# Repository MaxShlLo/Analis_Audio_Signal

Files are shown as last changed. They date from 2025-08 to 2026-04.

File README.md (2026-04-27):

# 🎵 Аудіо Спектроаналізатор

**Аудіо спектроаналізатор** — це пристрій, який візуалізує навколишній звук у реальному часі. 

За допомогою мікрофона він вловлює звуки із зовнішнього середовища (музику з колонок, голос, шум). Мікроконтролер оцифровує цей аналоговий сигнал, обробляє його за допомогою алгоритму Швидкого перетворення Фур'є (FFT) і виводить результат — спектр частот від басів до високих нот — на чотири світлодіодні матриці 8х8 у вигляді динамічних стовпчиків.

---
## 📂 Структура проєкту
- 📂 **Analis_Audio_Signal_ARDUINO** — Початкова версія коду для плат Arduino.
- 📂 **Audio_Spectrum_Analyzer_AltiumDesigner** — Схема та трасування друкованої плати (PCB), розроблена в Altium Designer.
- 📂 **vs-code** — Оптимізований модульний C-код для мікроконтролера STM8S103F3P6, налаштований для збірки через VS Code.

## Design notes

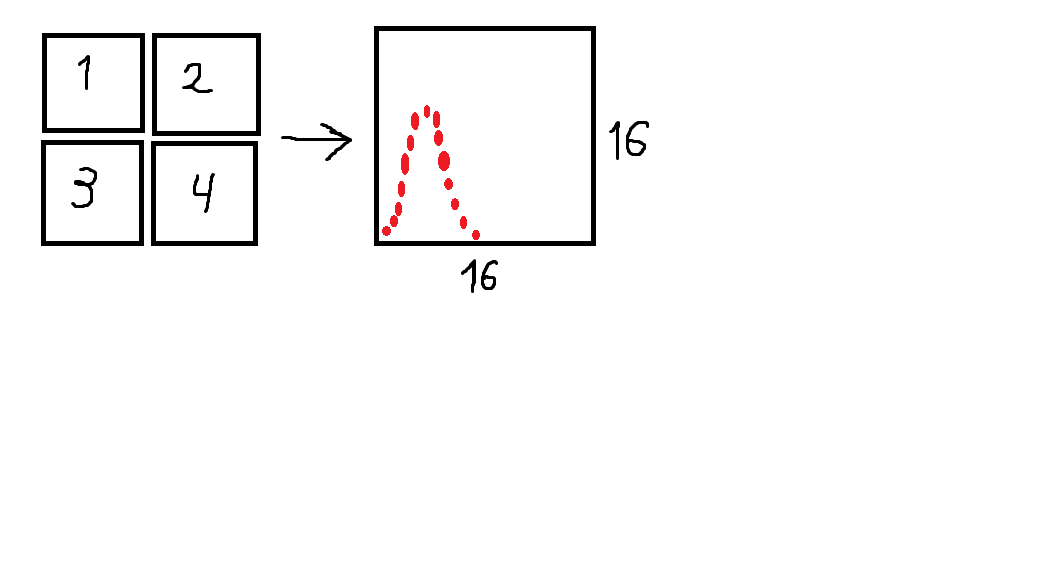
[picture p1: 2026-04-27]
FHT.png

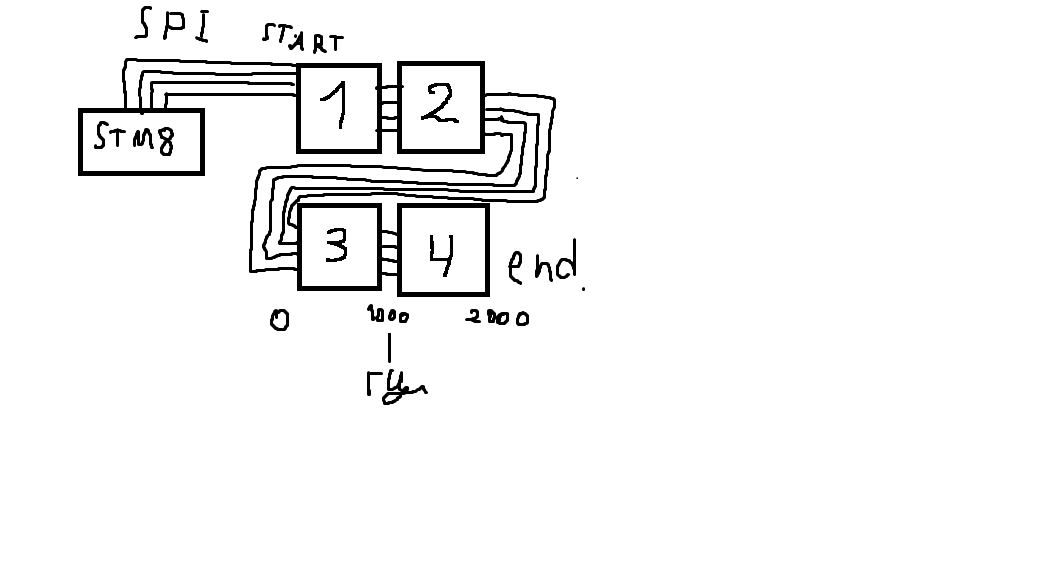
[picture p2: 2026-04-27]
SPI.png

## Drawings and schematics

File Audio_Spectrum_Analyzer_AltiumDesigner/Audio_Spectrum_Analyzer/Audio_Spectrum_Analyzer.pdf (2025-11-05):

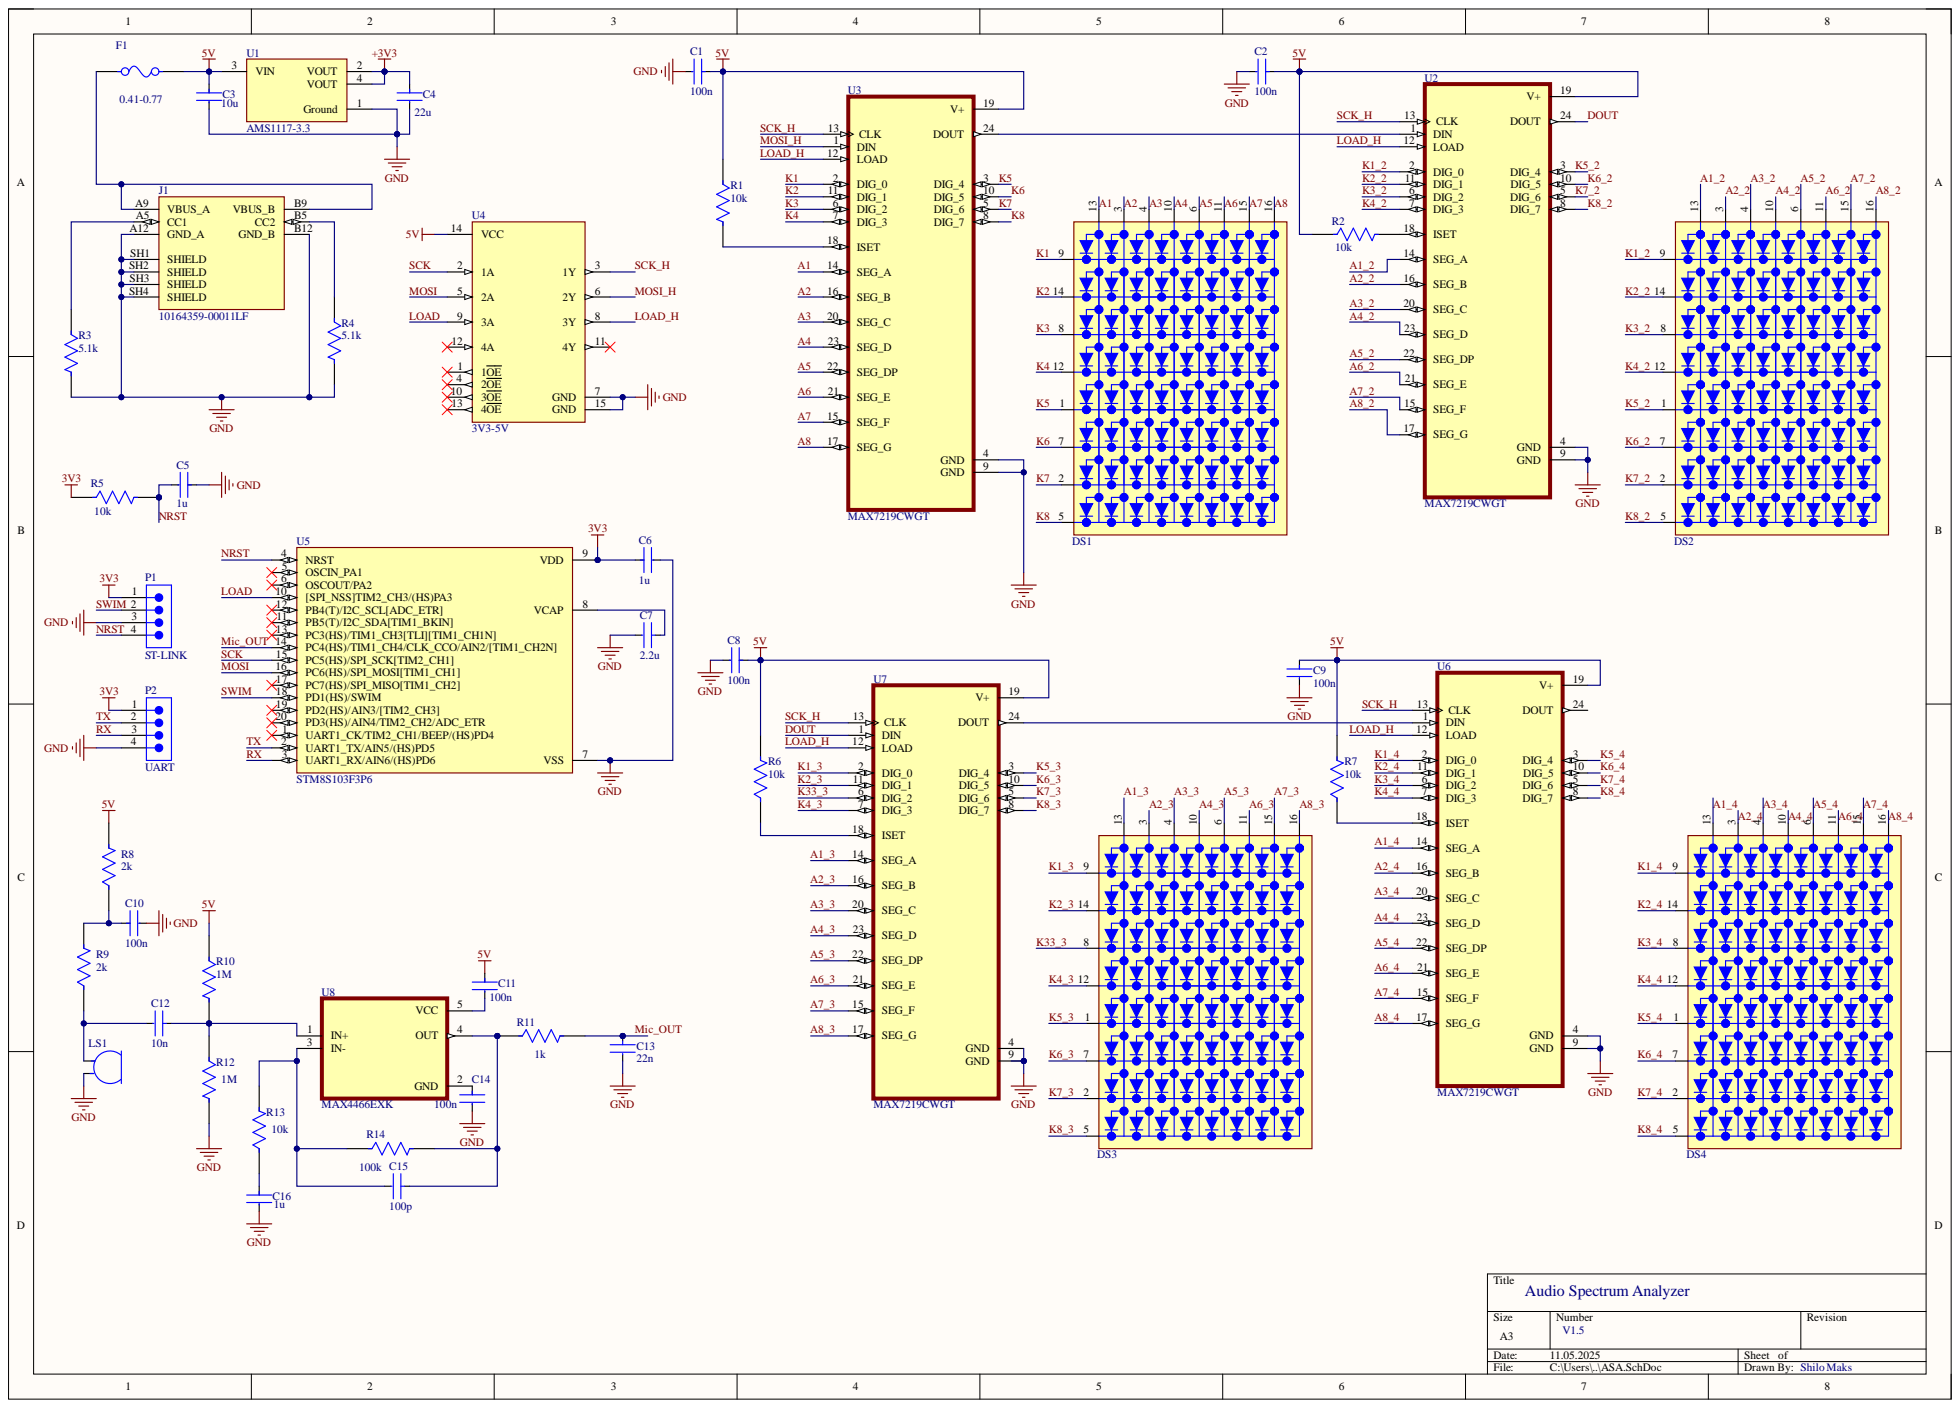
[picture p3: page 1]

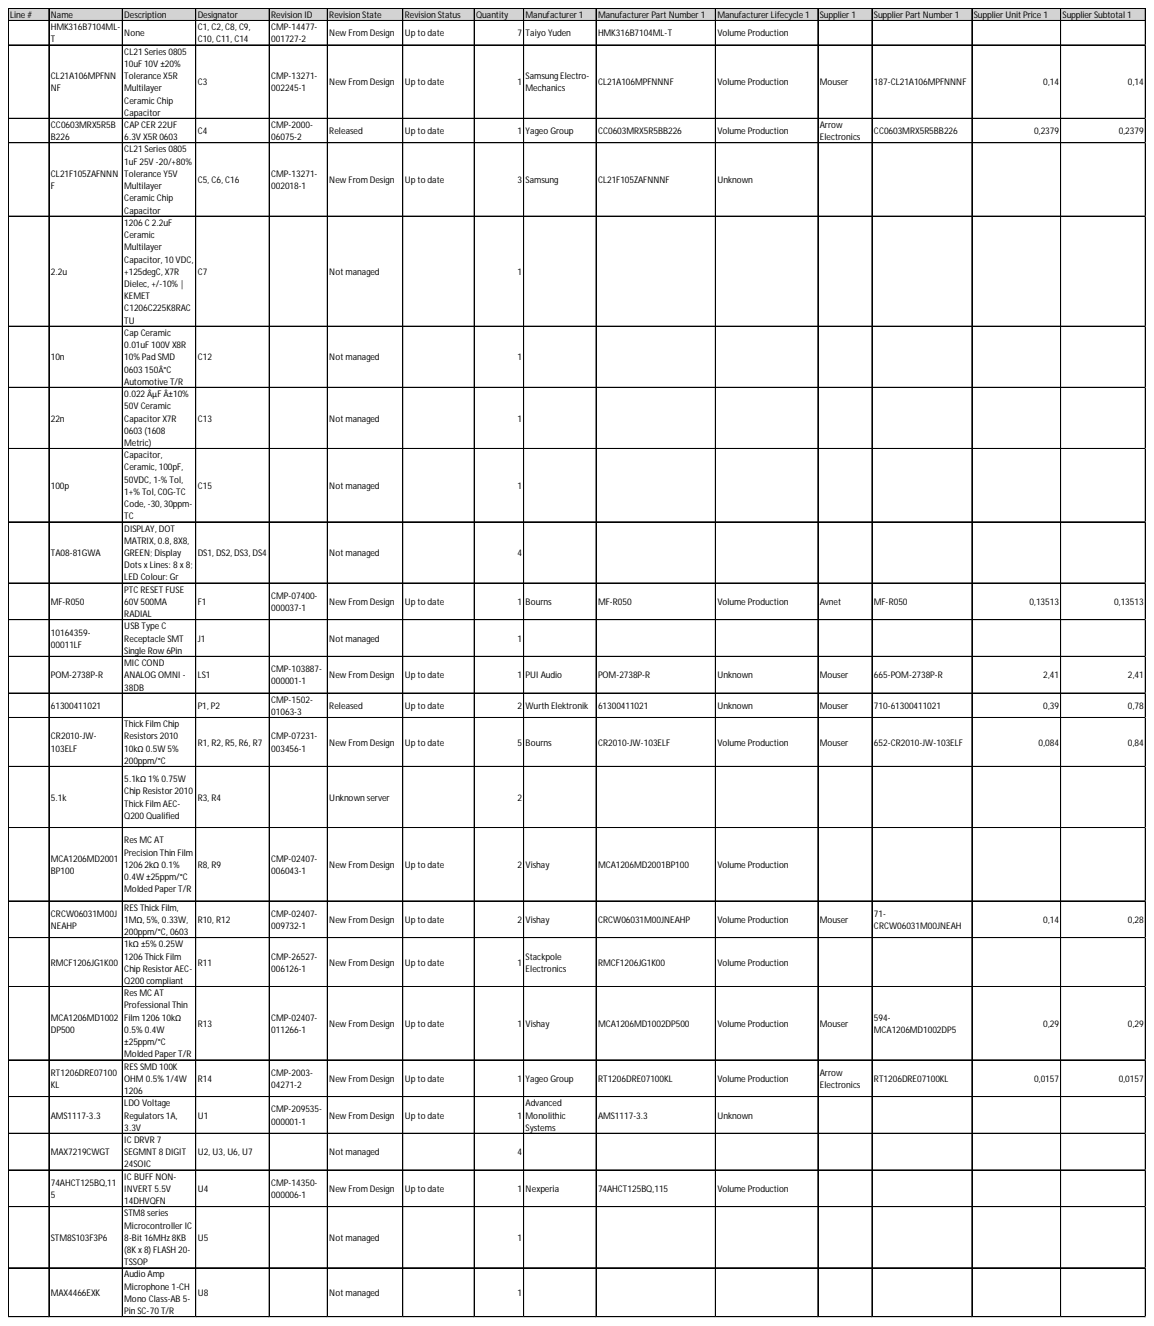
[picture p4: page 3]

Line # | Name | Description | Designator | Revision ID | Revision State | Revision Status | Quantity | Manufacturer 1 | Manufacturer Part Number 1 | Manufacturer Lifecycle 1 | Supplier 1 | Supplier Part Number 1 | Supplier Unit Price 1 | Supplier Subtotal 1

HMK316B7104ML-T | None | C1, C2, C8, C9, C10, C11, C14 | CMP-14477-001727-2 | New From Design | Up to date | 7 | Taiyo Yuden | HMK316B7104ML-T | Volume Production

CL21A106MPFNN NF | CL21 Series 0805 10uF 10V ±20% Tolerance X5R Multilayer Ceramic Chip Capacitor | C3 | CMP-13271-002245-1 | New From Design | Up to date | 1 | Samsung Electro-Mechanics | CL21A106MPFNNNF | Volume Production | Mouser | 187-CL21A106MPFNNNF | 0,14 | 0,14

CC0603MRX5R5B B226 | CAP CER 22UF 6.3V X5R 0603 | C4 | CMP-2000-06075-2 | Released | Up to date | 1 | Yageo Group | CC0603MRX5R5BB226 | Volume Production | Arrow Electronics | CC0603MRX5R5BB226 | 0,2379 | 0,2379

CL21F105ZAFNNN F | CL21 Series 0805 1uF 25V -20/+80% Tolerance Y5V Multilayer Ceramic Chip Capacitor | C5, C6, C16 | CMP-13271-002018-1 | New From Design | Up to date | 3 | Samsung | CL21F105ZAFNNNF | Unknown

2.2u | 1206 C 2.2uF Ceramic Multilayer Capacitor, 10 VDC, +125degC, X7R Dielec, +/-10% | KEMET C1206C225K8RAC TU | C7 | | Not managed | | 1

10n | Cap Ceramic 0.01uF 100V X8R 10% Pad SMD 0603 150Â°C Automotive T/R | C12 | | Not managed | | 1

22n | 0.022 ÂµF Â±10% 50V Ceramic Capacitor X7R 0603 (1608 Metric) | C13 | | Not managed | | 1

100p | Capacitor, Ceramic, 100pF, 50VDC, 1-% Tol, 1+% Tol, C0G-TC Code, -30, 30ppm-TC | C15 | | Not managed | | 1

TA08-81GWA | DISPLAY, DOT MATRIX, 0.8, 8X8, GREEN; Display Dots x Lines: 8 x 8; LED Colour: Gr | DS1, DS2, DS3, DS4 | | Not managed | | 4

MF-R050 | PTC RESET FUSE 60V 500MA RADIAL | F1 | CMP-07400-000037-1 | New From Design | Up to date | 1 | Bourns | MF-R050 | Volume Production | Avnet | MF-R050 | 0,13513 | 0,13513

10164359-00011LF | USB Type C Receptacle SMT Single Row 6Pin | J1 | | Not managed | | 1

POM-2738P-R | MIC COND ANALOG OMNI -38DB | LS1 | CMP-103887-000001-1 | New From Design | Up to date | 1 | PUI Audio | POM-2738P-R | Unknown | Mouser | 665-POM-2738P-R | 2,41 | 2,41

61300411021 | | P1, P2 | CMP-1502-01063-3 | Released | Up to date | 2 | Wurth Elektronik | 61300411021 | Unknown | Mouser | 710-61300411021 | 0,39 | 0,78

CR2010-JW-103ELF | Thick Film Chip Resistors 2010 10kΩ 0.5W 5% 200ppm/°C | R1, R2, R5, R6, R7 | CMP-07231-003456-1 | New From Design | Up to date | 5 | Bourns | CR2010-JW-103ELF | Volume Production | Mouser | 652-CR2010-JW-103ELF | 0,084 | 0,84

5.1k | 5.1kΩ 1% 0.75W Chip Resistor 2010 Thick Film AEC-Q200 Qualified | R3, R4 | | Unknown server | | 2

MCA1206MD2001 BP100 | Res MC AT Precision Thin Film 1206 2kΩ 0.1% 0.4W ±25ppm/°C Molded Paper T/R | R8, R9 | CMP-02407-006043-1 | New From Design | Up to date | 2 | Vishay | MCA1206MD2001BP100 | Volume Production

CRCW06031M00J NEAHP | RES Thick Film, 1MΩ, 5%, 0.33W, 200ppm/°C, 0603 | R10, R12 | CMP-02407-009732-1 | New From Design | Up to date | 2 | Vishay | CRCW06031M00JNEAHP | Volume Production | Mouser | 71-CRCW06031M00JNEAH | 0,14 | 0,28

RMCF1206JG1K00 | 1kΩ ±5% 0.25W 1206 Thick Film Chip Resistor AEC-Q200 compliant | R11 | CMP-26527-006126-1 | New From Design | Up to date | 1 | Stackpole Electronics | RMCF1206JG1K00 | Volume Production

MCA1206MD1002 DP500 | Res MC AT Professional Thin Film 1206 10kΩ 0.5% 0.4W ±25ppm/°C Molded Paper T/R | R13 | CMP-02407-011266-1 | New From Design | Up to date | 1 | Vishay | MCA1206MD1002DP500 | Volume Production | Mouser | 594-MCA1206MD1002DP5 | 0,29 | 0,29

RT1206DRE07100 KL | RES SMD 100K OHM 0.5% 1/4W 1206 | R14 | CMP-2003-04271-2 | New From Design | Up to date | 1 | Yageo Group | RT1206DRE07100KL | Volume Production | Arrow Electronics | RT1206DRE07100KL | 0,0157 | 0,0157

AMS1117-3.3 | LDO Voltage Regulators 1A, 3.3V | U1 | CMP-209535-000001-1 | New From Design | Up to date | 1 | Advanced Monolithic Systems | AMS1117-3.3 | Unknown

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

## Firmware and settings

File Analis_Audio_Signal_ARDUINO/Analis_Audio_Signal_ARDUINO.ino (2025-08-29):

// -------------------------------- НАСТРОЙКИ --------------------------------
// матрица
#define BRIGHTNESS 7     // яркость матрицы (0 - 15)

// сигнал
#define INPUT_GAIN 28    // коэффициент усиления входного сигнала
#define LOW_PASS 37       // нижний порог чувствительности шумов (нет скачков при отсутствии звука)
#define MAX_COEF 1.25      // коэффициент, который делает "максимальные" пики чуть меньше максимума, для более приятного восприятия
#define NORMALIZE 0       // нормализовать пики (столбики низких и высоких частот будут одинаковой длины при одинаковой громкости) (1 вкл, 0 выкл)

// анимация
#define SMOOTH 0.5        // плавность движения столбиков (0 - 1)
#define DELAY 6           // задержка между обновлениями матрицы (периодичность основного цикла), миллиисекунды

// громкость
#define DEF_GAIN 200       // максимальный порог по умолчанию (при MANUAL_GAIN или AUTO_GAIN игнорируется)
#define MANUAL_GAIN 0     // ручная настройка потенциометром на громкость (1 вкл, 0 выкл)
#define AUTO_GAIN 1       // автонастройка по громкости (экспериментальная функция) (1 вкл, 0 выкл)

// точки максимума
#define MAX_DOTS 1        // включить/выключить отрисовку точек максимума (1 вкл, 0 выкл)
#define FALL_DELAY 250     // скорость падения точек максимума (задержка, миллисекунды)
#define FALL_PAUSE 400    // пауза перед падением точек максимума, миллисекунды

// массив тонов, расположены примерно по параболе. От 80 Гц до 16 кГц
byte posOffset[33] = {
  2, 3, 4, 5, 6, 7, 8, 9, 10, 11, 12, 13, 14, 15, 20, 25, 32, 36, 40, 44, 48, 52, 57, 62, 67, 72, 78, 84, 90, 96, 102, 108, 120
};
// -------------------------------- НАСТРОЙКИ --------------------------------

// ---------------------- ПИНЫ ----------------------
// для увеличения точности уменьшаем опорное напряжение,
// выставив EXTERNAL и подключив Aref к выходу 3.3V на плате через делитель
// GND ---[10-20 кОм] --- REF --- [10 кОм] --- 3V3

// Матрица: CS -> 10 / CLK -> 13 / DIN -> 11
#define AUDIO_IN 0         // пин, куда подключен звук
#define POT_PIN 7          // пин потенциометра настройки (если нужен MANUAL_GAIN)
// ---------------------- ПИНЫ ----------------------

// --------------- ДЛЯ РАЗРАБОТЧИКОВ ---------------
#define MATR_NUM 4        // количество матриц последовательно
#define FHT_N 256         // ширина спектра х2
#define LOG_OUT 1
#include <FHT.h>           // преобразование Хартли
#include <SPI.h>
#include <Adafruit_GFX.h>
#include <Max72xxPanel.h>
Max72xxPanel matrix = Max72xxPanel(10, 4, 1);

#define cbi(sfr, bit) (_SFR_BYTE(sfr) &= ~_BV(bit))
#define sbi(sfr, bit) (_SFR_BYTE(sfr) |= _BV(bit))

int gain = DEF_GAIN;   // усиление по умолчанию
unsigned long gainTimer, fallTimer;
byte maxValue;
float k = 0.05, maxValue_f = 0.0;
int maxLevel[32];
byte posLevel_old[32];
unsigned long timeLevel[32], mainDelay;
boolean fallFlag;
// --------------- ДЛЯ РАЗРАБОТЧИКОВ ---------------

void setup() {
  // поднимаем частоту опроса аналогового порта до 38.4 кГц, по теореме
  // Котельникова (Найквиста) максимальная частота дискретизации будет 19 кГц
  // http://yaab-arduino.blogspot.ru/2015/02/fast-sampling-from-analog-input.html
  sbi(ADCSRA, ADPS2);
  cbi(ADCSRA, ADPS1);
  sbi(ADCSRA, ADPS0);

  //analogReference(EXTERNAL);

  Serial.begin(9600);
  matrix.setIntensity(BRIGHTNESS);
  for (byte i = 0; i < MATR_NUM; i++) {
    // матрицы расположены криво, здесь поворачиваем
    matrix.setRotation(i, 1);
  }
  matrix.fillScreen(LOW);
  matrix.write();
}

void loop() {

int sample = analogRead(A0); // або AUDIO_IN
  Serial.println(sample);
  delay(10);

  
  if (millis() - mainDelay > DELAY - 2) {     // итерация главного цикла
    mainDelay = millis();

    analyzeAudio();   // функция FHT, забивает массив fht_log_out[] величинами по спектру

    for (int i = 0; i < 128; i ++) {
      // вот здесь сразу фильтруем весь спектр по минимальному LOW_PASS
     // static int noiseFloor = LOW_PASS;
      //noiseFloor = noiseFloor * 1.9 + fht_log_out[i] * 0.1; // плавно оновлюємо
      //if (fht_log_out[i] < noiseFloor + 5) fht_log_out[i] = 0;
      if (fht_log_out[i] < LOW_PASS) fht_log_out[i] = 0;

      // усиляем сигнал
      fht_log_out[i] = (float)fht_log_out[i] * INPUT_GAIN;

      // уменьшаем громкость высоких частот (пропорционально частоте) если включено
      if (NORMALIZE) fht_log_out[i] = (float)fht_log_out[i] / ((float)1 + (float)i / 128);
    }
    maxValue = 0;
    matrix.fillScreen(LOW);
    delay(2);///////////////////СУКАДИЛЕЙ//////БЕЗ НЕГО МАТРИЦА НАЧИНАЕТ КОСОЖОПИТЬ///////////
    for (byte pos = 0; pos < MATR_NUM * 8; pos++) {    // для кажого столбца матрицы
    
    // Розрахунок індекса з інверсією в межах кожної матриці
      byte matrixIndex = pos / 8;          // номер матриці
      byte columnInMatrix = pos % 8;       // позиція в матриці
      byte drawPos = matrixIndex * 8 + (7 - columnInMatrix);  // інверсія всередині матриці

      int posLevel = fht_log_out[posOffset[pos]];
      byte linesBetween;
      if (pos > 0 && pos < MATR_NUM * 8) {
        linesBetween = posOffset[pos] - posOffset[pos - 1];
        for (byte i = 0; i < linesBetween; i++) {  // от предыдущей полосы до текущей
          posLevel += (float) ((float)i / linesBetween) * fht_log_out[posOffset[pos] - linesBetween + i];
        }
        linesBetween = posOffset[pos + 1] - posOffset[pos];
        for (byte i = 0; i < linesBetween; i++) {  // от предыдущей полосы до текущей
          posLevel += (float) ((float)i / linesBetween) * fht_log_out[posOffset[pos] + linesBetween - i];
        }
      }
      // найти максимум из пачки тонов
      if (posLevel > maxValue) maxValue = posLevel;

      // фильтрация длины столбиков, для их плавного движения
      posLevel = posLevel_old[pos] * SMOOTH + posLevel * (1 - SMOOTH);
      posLevel_old[pos] = posLevel;

      // преобразовать значение величины спектра в диапазон 0..7 с учётом настроек
      posLevel = map(posLevel, LOW_PASS, gain, 0, 7);
      posLevel = constrain(posLevel, 0, 7);

      // если столбик больше нуля, то начать линию с координаты (pos, 7) и рисовать в (pos, 7 - значение)
      if (posLevel > 0) matrix.drawLine(drawPos, 7, drawPos, 7 - posLevel, HIGH);

      if (posLevel > 0 && posLevel > maxLevel[drawPos]) {    // если для этой полосы есть максимум, который больше предыдущего
        maxLevel[drawPos] = posLevel;                        // запомнить его
        timeLevel[drawPos] = millis();                       // запомнить время
      }

      // если точка максимума выше нуля (или равна ему) - включить пиксель
      if (MAX_DOTS && maxLevel[pos] >= 0) matrix.drawPixel(drawPos, 7 - maxLevel[drawPos], HIGH);

      if (fallFlag) {                                           // если падаем на шаг
        if ((long)millis() - timeLevel[pos] > FALL_PAUSE) {     // если максимум держался на своей высоте дольше FALL_PAUSE
          if (maxLevel[pos] >= 0) maxLevel[pos]--;              // уменьшить высоту точки на 1
          // внимание! Принимает минимальное значение -1 !
        }
      }
    }
    matrix.write();  // отправить на матрицу

    fallFlag = 0;                                 // сбросить флаг падения
    if (millis() - fallTimer > FALL_DELAY) {      // если настало время следующего падения
      fallFlag = 1;                               // поднять флаг
      fallTimer = millis();
    }

    // если разрешена ручная настройка уровня громкости
    if (MANUAL_GAIN) gain = map(analogRead(POT_PIN), 0, 1023, 0, 150);

    // если разрешена авто настройка уровня громкости
    if (AUTO_GAIN) {
      if (millis() - gainTimer > 10) {      // каждые 10 мс
        maxValue_f = maxValue * k + maxValue_f * (1 - k);
        // если максимальное значение больше порога, взять его как максимум для отображения
        if (maxValue_f > LOW_PASS) gain = (float)MAX_COEF * log(1 + maxValue_f) * 50;
        // если нет, то взять порог побольше, чтобы шумы вообще не проходили
        else gain = 100;
        gainTimer = millis();
      }
    }
  }
}

int analogReadAvg(byte pin) {
  int sum = 0;
  for (byte j = 0; j < 4; j++) sum += analogRead(pin); // 4 сэмпла
  return sum >> 2; // поділити на 4
}


void analyzeAudio() {
  for (int i = 0 ; i < FHT_N ; i++) {
    int sample = analogRead(AUDIO_IN);
    fht_input[i] = sample; // put real data into bins
    //fht_input[i] = analogReadAvg(AUDIO_IN);
  }
  fht_window();  // window the data for better frequency response
  fht_reorder(); // reorder the data before doing the fht
  fht_run();     // process the data in the fht
  fht_mag_log(); // take the output of the fht
}

/*
   Алгоритм работы:
   Анализ спектра, на выходе имеем массив величин полос спектра (128 полос)
   Фильтрация по нижним значениям для каждой полосы (128 полос)
   Переход от 128 полос к 16 полосам с сохранением межполосных значений по линейной зависимости
   Поиск максимумов для коррекции высоты столбиков на матрице
   Перевод чистого "веса" полосы к высоте матрицы
   Отправка полос на матрицу
   Расчёт позиций точек максимума и отправка их на мтарицу

   Мимоходом фильтрация верхних пиков, коррекция высоты столбиков от громкости и прочее
*/

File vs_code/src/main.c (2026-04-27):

/* main.c - STM8S103F3P6 (FFT ІДЕАЛЬНА ПЛАВНІСТЬ ТА СУПЕР ЧУТЛИВІСТЬ) */
#include "iostm8s103.h"
#include "matrix.h"
#include "fft.h"

const unsigned char bin_start[16] = {1, 2, 3, 4, 5, 6, 8, 10, 12, 15, 18, 22, 27, 33, 40, 49};
const unsigned char bin_end[16]   = {1, 2, 3, 4, 5, 7, 9, 11, 14, 17, 21, 26, 32, 39, 48, 63};

// Додатковий масив для сирих піків перед малюванням
unsigned int raw_peaks[16]; 
unsigned char smooth_mag[16]; // Масив для плавності (SMOOTH)

/* НАЛАШТУВАННЯ ЧУТЛИВОСТІ */
#define LOW_PASS  3    // Поріг шуму (знижено до мінімуму)
#define MIC_GAIN  25    // НОВЕ: Програмний підсилювач (Множник сигналу! 4 або 5)

// ЕКВАЛАЙЗЕР: Підсилюємо баси (перші 4 стовпчики)
const unsigned char eq_curve[16] = {
    26, 20, 16, 14, 12, 12, 10, 10, 8, 8, 7, 7, 6, 6, 6, 6
};

/* -------- ГЛОБАЛЬНІ ЗМІННІ ДЛЯ АВТОПІДСИЛЕННЯ (AGC) -------- */
unsigned int dynamic_max = 30;   
unsigned char frame_counter = 0; 

void init_gpio(void) {
    PA_DDR |= (1 << 3); PA_CR1 |= (1 << 3); LOAD_HIGH();
    PC_DDR |= (1 << 5) | (1 << 6); PC_CR1 |= (1 << 5) | (1 << 6);
}

void init_adc(void) {
    PC_DDR &= ~(1 << 4);
    PC_CR1 &= ~(1 << 4);
    ADC_CR1 = 0x00;
    ADC_CR2 = 0x08; 
    ADC_CSR = 0x02;
    ADC_CR1 |= 0x01;
}

/* -------- ВЛАСНИЙ МІНІ-UART -------- */
void init_uart(void) {
    // Налаштовуємо пін PD5 (TX) як вихід
    PD_DDR |= (1 << 5);
    PD_CR1 |= (1 << 5);
    
    // Швидкість 115200 бод (для стандартної частоти 2 МГц)
    // Формула: 2 000 000 / 115200 = 17.36 (Hex: 0x0011)
    UART1_BRR2 = 0x01;
    UART1_BRR1 = 0x01;
    
    // Вмикаємо передавач (TX)
    UART1_CR2 = (1 << 3);
}

void uart_tx(unsigned char data) {
    while (!(UART1_SR & 0x80)); // Чекаємо, поки буфер звільниться
    UART1_DR = data;
}

void uart_print(const char *str) {
    while (*str) {
        uart_tx(*str++);
    }
}

void uart_print_int(unsigned int num) {
    char buf[6];
    int i = 0;
    if (num == 0) {
        uart_tx('0');
        return;
    }
    while (num > 0) {
        buf[i++] = (num % 10) + '0';
        num /= 10;
    }
    while (i > 0) {
        uart_tx(buf[--i]);
    }
}


void show_spectrum(void) {
    unsigned char col, i, height;
    unsigned int max_val, frame_peak;
    unsigned long calc_val;

    frame_peak = 0;
    
    /* ПРОХІД 1: Збираємо піки */
    for (col = 0; col < 16; col++) {
        max_val = 0;
        for (i = bin_start[col]; i <= bin_end[col]; i++) {
            if (test_mag[i] > max_val) {
                max_val = test_mag[i];
            }
        }
        
        // СПРАВЖНІЙ ШУМОДАВ: Відсікаємо електричний шум ДО множення!
        // Якщо сигнал менше LOW_PASS, ми його взагалі ігноруємо.
        if (max_val <= LOW_PASS) {
            max_val = 0;
        }
        
        calc_val = (unsigned long)max_val * eq_curve[col] * MIC_GAIN / 10;
        if (calc_val > 60000) calc_val = 60000; 
        max_val = (unsigned int)calc_val; 

        raw_peaks[col] = max_val;
        
        if (max_val > frame_peak) {
            frame_peak = max_val;
        }
    }
    
    /* РОЗУМНЕ АВТОПІДСИЛЕННЯ З ЗАХИСТОМ ВІД ТИШІ */
    if (frame_peak > dynamic_max) {
        dynamic_max = (dynamic_max * 3 + frame_peak) >> 2;
    } else {
        if (dynamic_max > 40) {
            // ЕКСПОНЕНЦІЙНЕ ПАДІННЯ: Віднімаємо 1/32 частину від самої стелі.
            // Якщо стеля 10000, вона впаде на 312 одразу!
            // Якщо стеля 100, вона впаде лише на 3.
            dynamic_max -= (dynamic_max >> 3) + 2; 
        }
    }

    /* ЖОРСТКЕ ГАСІННЯ В ТИШІ */
    if (frame_peak == 0) {
        // Якщо звуку немає взагалі, плавно "ховаємо" залишки хвилі вниз
        for (col = 0; col < 16; col++) {
            smooth_mag[col] = (unsigned char)(((unsigned int)smooth_mag[col] * 3) >> 2);
            height = (unsigned char)(((unsigned int)smooth_mag[col] * 16) / 256);
            draw_column(col, height);
        }
        max_flush();
        return; // Виходимо з функції, далі рахувати немає сенсу
    }

    /* ПРОХІД 2: Асиметрична плавність */
    for (col = 0; col < 16; col++) {
        calc_val = ((unsigned long)raw_peaks[col] * 255) / dynamic_max; 
        if (calc_val > 255) calc_val = 255;

        if (calc_val > smooth_mag[col]) {
            smooth_mag[col] = (unsigned char)calc_val; 
        } else {
            smooth_mag[col] = (unsigned char)(((unsigned int)smooth_mag[col] * 3 + calc_val) >> 2);
        }

        height = (unsigned char)(((unsigned int)smooth_mag[col] * 16) / 256);
        draw_column(col, height);
    }

    /* ВИВІД В UART ДЛЯ НАЛАШТУВАННЯ */
    uart_print("Peak: ");
    uart_print_int(frame_peak);
    uart_print(" | AGC Стеля: ");
    uart_print_int(dynamic_max);
    uart_print("\r\n"); // Перехід на новий рядок

    max_flush();
}

/* -------- MAIN -------- */
void main(void) {
    unsigned char i;
    unsigned char adc_l;
    unsigned int adc_h;
    volatile unsigned char delay;
    long dc_sum;
    int dc_offset;
    long val;

    for (i = 0; i < 16; i++) smooth_mag[i] = 0;

    init_gpio();
    init_spi();
    init_adc();
    init_uart();
    max_init();
    max_clear();

    while (1) {
        dc_sum = 0;
        
        /* 1. ЧИТАЄМО ЗВУК З МІКРОФОНА */
        for (i = 0; i < 128; i++) {
            ADC_CSR &= ~0x80;
            ADC_CR1 |= 0x01;
            while (!(ADC_CSR & 0x80));

            adc_l = ADC_DRL;
            adc_h = ADC_DRH;
            
            test_real[i] = (int)((adc_h << 8) | adc_l);
            test_imag[i] = 0; 
            
            dc_sum += test_real[i];

            for (delay = 0; delay < 15; delay++); 
        }

        /* 2. ВІДРІЗАЄМО ТИШУ ТА РОБИМО ПРОГРАМНЕ ПІДСИЛЕННЯ */
        dc_offset = (int)(dc_sum >> 7); 
        for (i = 0; i < 128; i++) {
            val = test_real[i] - dc_offset; 
            
            val = val >> 1;
            
            // Запобіжник (лімітер), щоб математика не вибухнула від гучного крику
            if (val > 150) val = 150;
            if (val < -150) val = -150;

            test_real[i] = (int)val; 
        }

        /* 3. ШВИДКЕ ПЕРЕТВОРЕННЯ ФУР'Є */
        fft_reorder();
        fft_run();
        fft_mag();

        /* 4. ВИВІД ІЗ ПЛАВНІСТЮ */
        show_spectrum();
    }
}

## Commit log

2025-08-11 ADD ARDUINO
2025-08-29 ADD Altium file
    [AJAXProject.PrjPcb, ASA.SchDoc, LDM-13488MI.SchLib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]
2025-09-03 MOD Altium_V1.1
    [ASA.SchDoc]
2025-09-03 Mod Altium_V1.2
    [ASA.SchDoc]
2025-09-23 Mod Altium_V1.3
    [ASA.SchDoc, Audio_Spectrum_Analyzer.PrjPcb, DISPLAY_TA08-81GWA.PcbLib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]
2025-10-23 MOD Altium_V1.4
    [ASA.SchDoc, Audio_Spectrum_Analyzer.PrjPcb, PCB2.PcbDoc]
2025-11-05 MOD Altium_V1.5 and ADD components in PCB
    [ASA.SchDoc, PCB1.PcbDoc, PCB2.PcbDoc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]
2026-01-20 Mod Altium
    [ASA.SchDoc, Audio_Spectrum_Analyzer.PrjPcb, DISPLAY_TA08-81GWA.PcbLib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]
2026-04-28 ADD Gerber Files
    [ASA.SchDoc, Audio_Spectrum_Analyzer.PrjPcb, PCB_ASA.PcbDoc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]
2026-05-03 MOD PCB
    [ASA.SchDoc, Audio_Spectrum_Analyzer.PrjPcb, PCB_ASA.PcbDoc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]
